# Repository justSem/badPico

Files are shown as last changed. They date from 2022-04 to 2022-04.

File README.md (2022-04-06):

# badPico!
An [RP2040](https://www.raspberrypi.com/products/rp2040/) mini-sized BadUSB clone

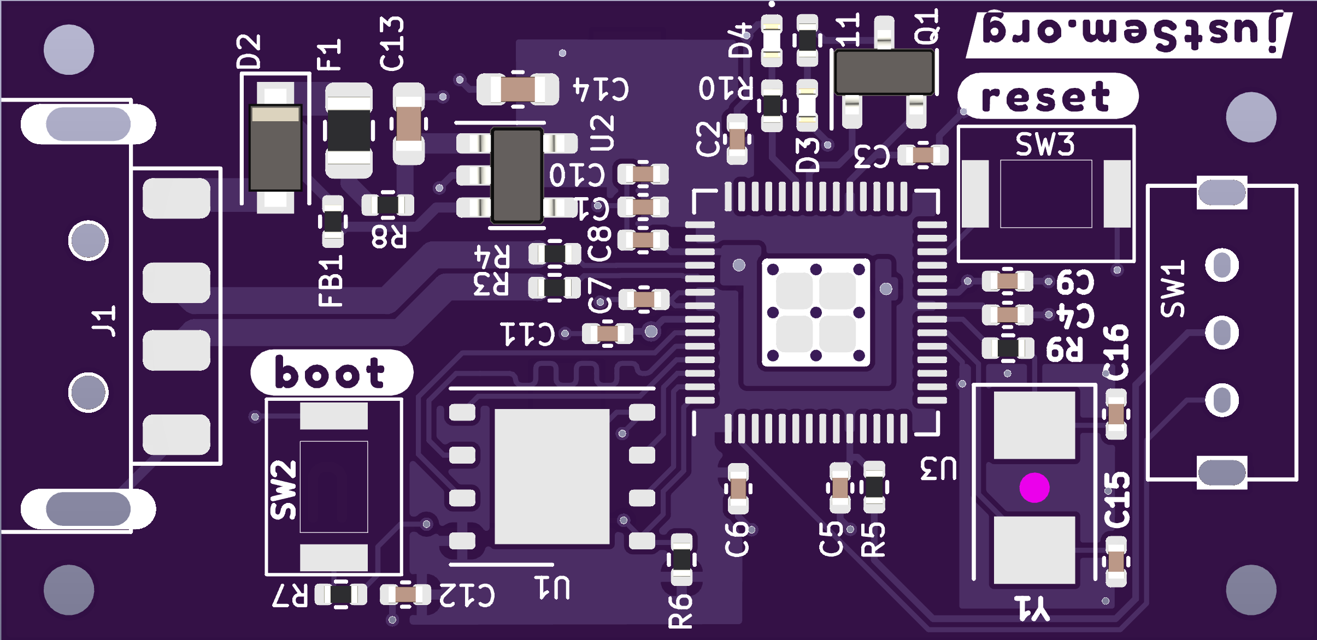
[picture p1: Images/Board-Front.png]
front

_Size: 19x39mm_

This tiny (19x34mm) device is just a common "Rubber Ducky" clone.

Without software this is just an RP2040-on-a-stick ;)

# Usage
A good starting point for this board is the [BadPico Repository](https://github.com/EvgeniGenchev/BadPico) by @EvgeniGenchev.

The board in general works identical to a Raspberry [Pi Pico](https://www.raspberrypi.com/products/raspberry-pi-pico/) and can be programmed as such.
However, due to the intended use-case the I/O pins are not available for usage with the exception of those listed below.

# PinOuts

| Designator	| GPIO  |  Type 	| Description 							|
| --- | ----- | --- | --- |
|  D4		| 25	| LED		| Status LED  							|
|  D3		| 24	| LED		| User-programmable LED 					|
| SW1		| 0	| Switch	| User-programmable switch. I use it as an 'arming' switch 	| 

# Bill of Materials (BoM)
| Name	| Designator	| Footprint	| Manufacturer		| Man. Part No.			|
| ----- | --- | --- | --- | --- |
| 27pF	| C15,C16	| C0402		| FH			| 0402CG270J500NT		|
| 100nF | C1-C9,C12	| C0402		| Yaego			| CC0402KRX7R7BB104		|
| 1uF	| C10,C11	| C0402		| Samsung		| CL05A105KQ5NNNC		|
| 10uF	| C13,C14	| C0603		| Samsung		| CL10A106MP8NNNC		| 
| Y	| Y1		| 5032		| Abracon		| ABMM2-12.000MHZ-E2-T 		|
| 24.7R	| R3,R4		| R0402		| FH			| RC-02W27R4FT 			|
| 330R	| R5		| R0402		| FOJAN			| FRC1206J331			|
| 1k	| R7,R9,R10,R11	| R0402		| Walsin		| MR04X102			|
| 100k	| R8		| R0402		| FH			| RS-03K104JT			|
| Flash	| U1		| WSON-8	| Winbond Elec		| W25Q128JVPIQ			|
| LDO	| U2		| TSOT-23-5	| Maxlinear		| SPX3819M5-L-3-3		|
| RP2040 | U3		| QFN-56	| Raspberry Pi		| RP2040			|
| FET	| Q1		| SOT-24	| Vishay		| Si2319CDS			|
| Diode	| D2		| SOD_123F	| Shandong		| 1N4002W			|
| LEDs	| D3,D4		| D0402		| Everlight		| 17-21/BHC-XL2M2TY/3T		|
| Fuse	| F1		| F0805		| LittelFuse		| 0805L050WR			|
| Bead	| FB1		| F0402		| Chillsin		| BBSY00100505101Y00		|
| USB	| J1		| Custom	| XKB Connectivity	| U217-041N-4BV81 		|
| SWT	| SW2,SW3	| Custom	| ALPS			| SKRKAEE020			|
| SWF	| SW1		| Custom	| Shou Han		| SK12D07VG4			|

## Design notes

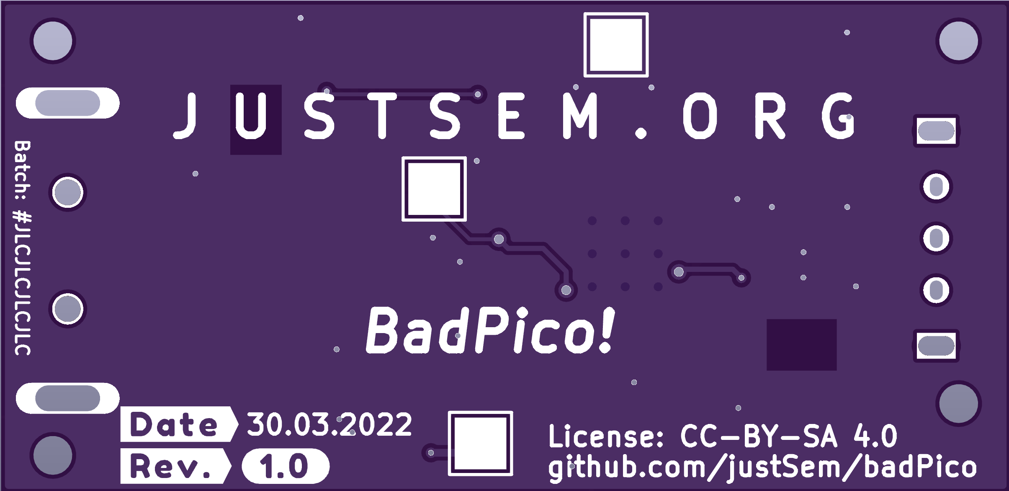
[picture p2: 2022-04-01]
Images/Board-Back.png

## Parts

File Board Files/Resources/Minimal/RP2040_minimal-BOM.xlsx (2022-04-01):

RP2040_minimal_r1 BOM
Item | Quantity | Reference | Part | Voltage | Current | Power | Material | Size | Tolerance | Manufacturer | Manuf. Part # | Description | Notes
1 | 3 | C1,C4,C17 | 10u | 16V |  |  | X5R | 0805_2012Metric | 10% | Murata | GRM21BR61C106KE15K | CAP CER 10UF 16V X5R 0805 | Or equivalent
2 | 2 | C2, C3 | 27p | 50V |  |  | C0G | 0402_1005Metric | 5% | Murata | GCM1555C1H270JA16D | CAP CER 27PF 50V C0G/NP0 0402 | Or equivalent
3 | 10 | C5, C6, C7, C9, C11, C12, C13, C14, C15, C16 | 100n | 25V |  |  | X7R | 0402_1005Metric | 10% | Murata | GRM155R71E104KE14J | CAP CER 0.1UF 25V X7R 0402 | Or equivalent
4 | 2 | C8, C10 | 1u | 10V |  |  | X6S | 0402_1005Metric | 10% | Murata | GRM155C81A105KA12D | CAP CER 1UF 10V X6S 0402 | Or equivalent
5 | 1 | J1 | USB_B_Micro |  |  |  |  |  |  | Amphenol | 10103594-0001LF | CONN RCPT USB2.0 MICRO B SMD R/A | Or equivalent
6 | 1 | J2 | 1x2 way header |  |  |  |  |  |  | Samtec | TSW-102-23-T-S | 2.54mm pin header 1x2 | Or equivalent
7 | 2 | J3, J4 | 2x18 way header |  |  |  |  |  |  | Samtec | TSW-118-23-T-D | 2.54mm pin header 2x18 | Or equivalent
8 | 2 | R1, R5 | 1k |  |  | 63mW |  | 0402_1005Metric | 1% | Yageo | RC0402FR-071KP | RES SMD 1K OHM 1% 1/16W 0402 | Or equivalent
9 | 1 | R2 | DNF |  |  |  |  | 0402_1005Metric |  |  |  |  | Do Not Fit
10 | 2 | R3, R4 | 27.4 |  |  | 63mW |  | 0402_1005Metric | 1% | Yageo | RC0402FR-0727R4L | RES SMD 27.4 OHM 1% 1/16W 0402 | Or equivalent
11 | 1 | U1 | NCP1117-3.3 |  |  |  |  | SOT-223-3 |  | ON Semiconductor | NCP1117ST33T3G | IC REG LINEAR 3.3V 1A SOT223
12 | 1 | U2 | W25Q128JVS |  |  |  |  | SOIC-8 |  | Winbond | W25Q128JVSIQ TR | IC FLASH 128M SPI 133MHZ 8SOIC
13 | 1 | U3 | RP2040 |  |  |  |  | QFN56 |  | Raspberry Pi | RP2040
14 | 1 | Y1 | ABLS-12.000MHZ-B4-T |  |  |  |  | HC49-US |  | Abracon | ABLS-12.000MHZ-B4-T | CRYSTAL 12.0000MHZ 18PF SMD

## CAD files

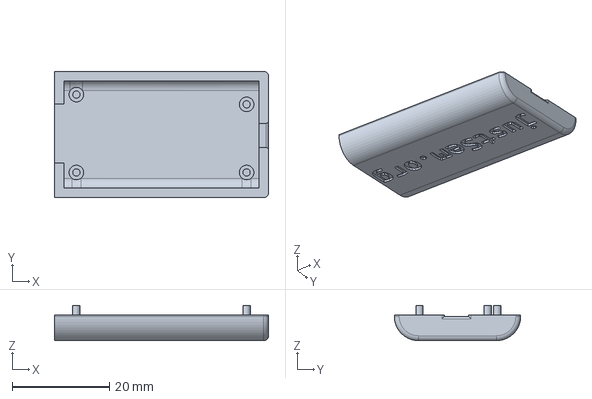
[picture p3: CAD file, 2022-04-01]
3D/BadPioco-Btm.step
44.0 x 26.0 x 7.25 mm

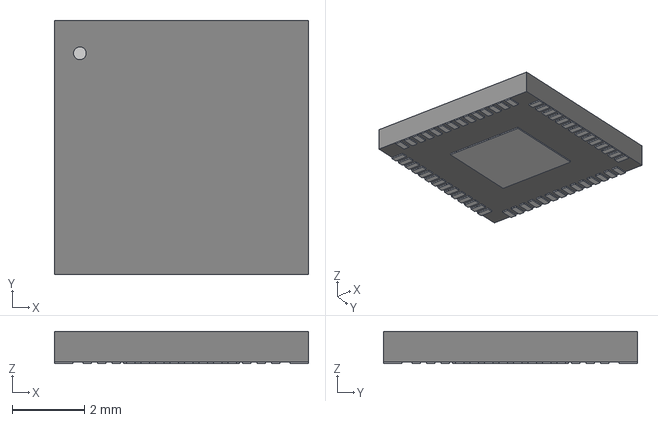
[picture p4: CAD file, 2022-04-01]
Board Files/Resources/Minimal/QFN56_7X7_RPI.step
7.01 x 7.01 x 0.892 mm

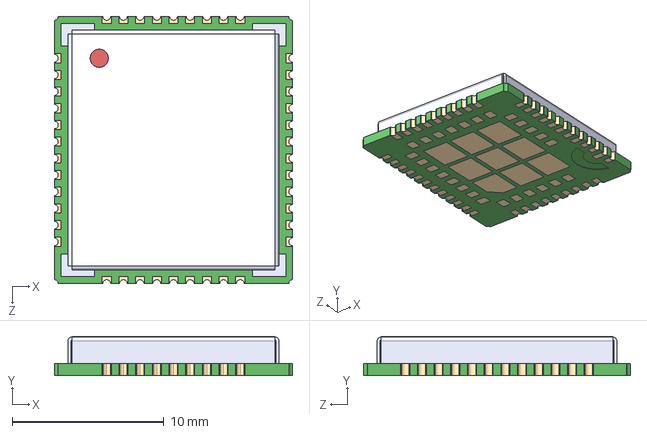
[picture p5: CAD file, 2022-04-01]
Board Files/Resources/SIM868/SIM868.step
15.7 x 2.60 x 17.6 mm

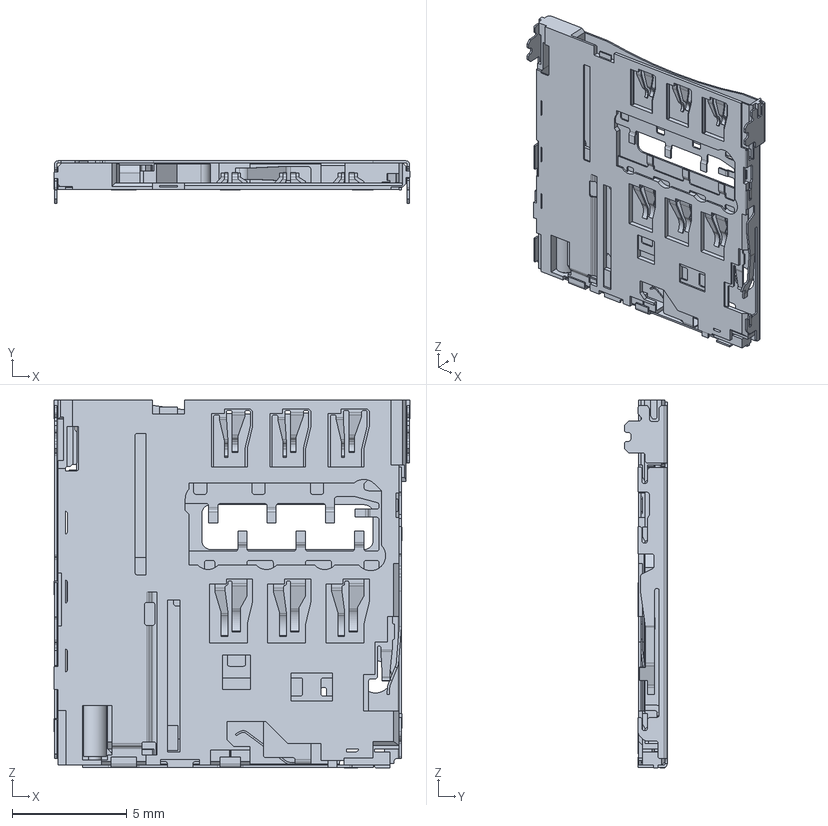
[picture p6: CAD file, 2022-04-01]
Board Files/Resources/ul_2822541-1/c-2822541-1-c-3d.stp
15.5 x 1.89 x 16.0 mm

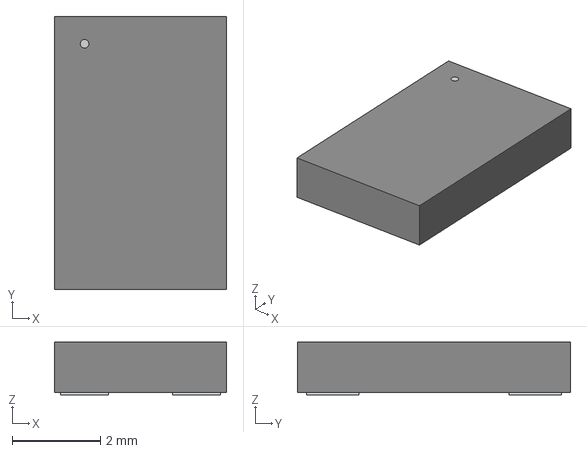
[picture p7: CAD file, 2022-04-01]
Board Files/Resources/ul_ABMM2-12-000MHZ-E2-T/CRYSTAL_ABMM2_ABR.step
3.91 x 6.20 x 1.20 mm

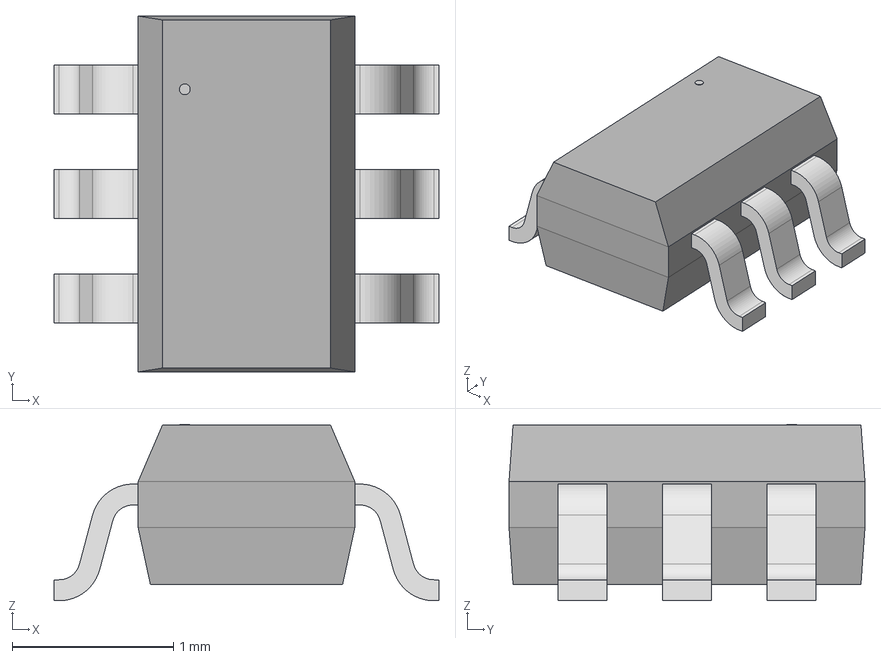
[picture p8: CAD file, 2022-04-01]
Board Files/Resources/ul_ESDA6V1-5W6/STEP/SOT323-6L_STM.step
2.39 x 2.21 x 1.09 mm

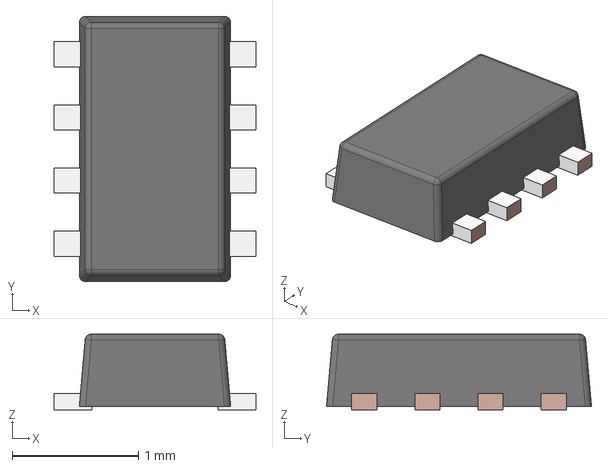
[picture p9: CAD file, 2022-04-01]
Board Files/Resources/ul_LM66200DRLR/STEP/DRL0008A.stp
1.60 x 2.10 x 0.6 mm
FRAME-DRL0008A
BODY-SOT

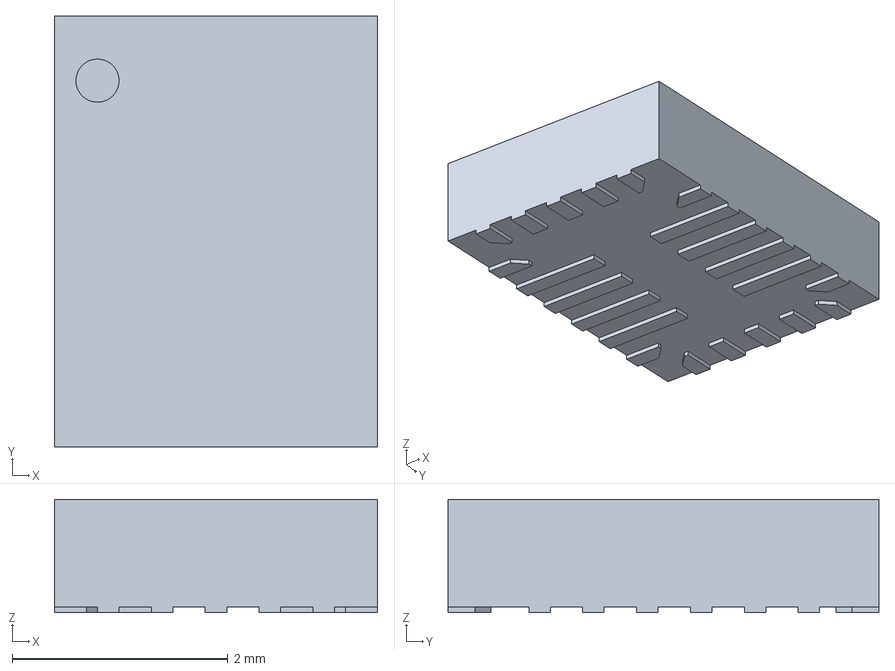
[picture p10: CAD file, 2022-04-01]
Board Files/Resources/ul_MP2624GL/FreeCad.step
3.00 x 4.00 x 1.05 mm

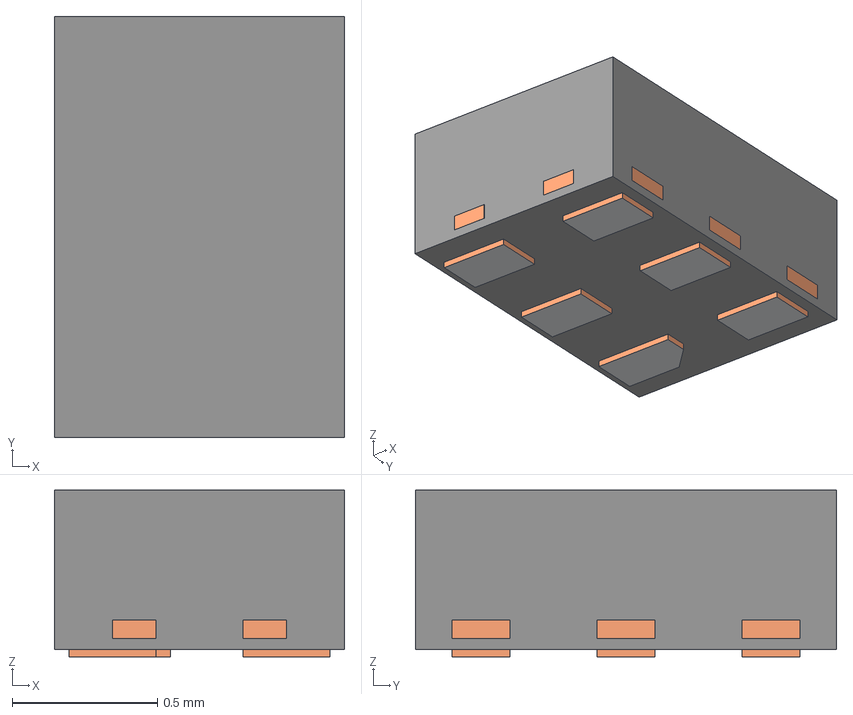
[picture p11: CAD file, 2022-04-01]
Board Files/Resources/ul_SN74LVC1G66DRYR/DRY0006A.stp
1.00 x 1.45 x 0.575 mm
BODY-SON
FRAME-DRY0006A
PIN1-ID

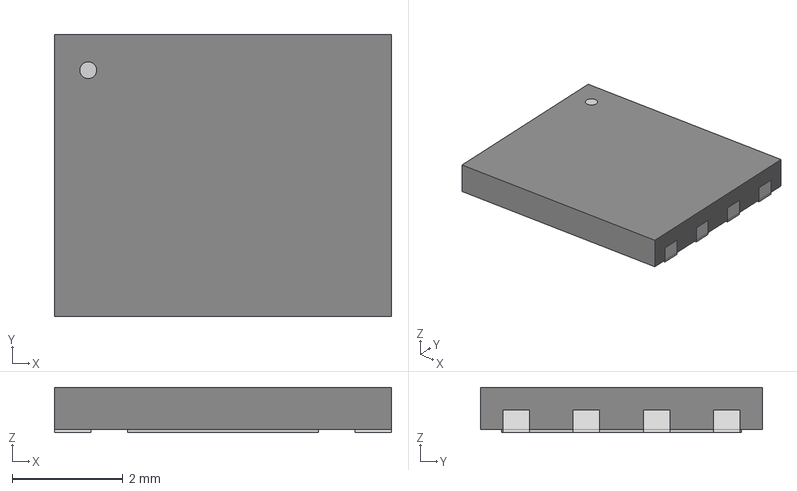
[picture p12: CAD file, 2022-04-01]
Board Files/Resources/Winbond_Flash/WSON-8_6X5_WIN.step
6.10 x 5.11 x 0.815 mm

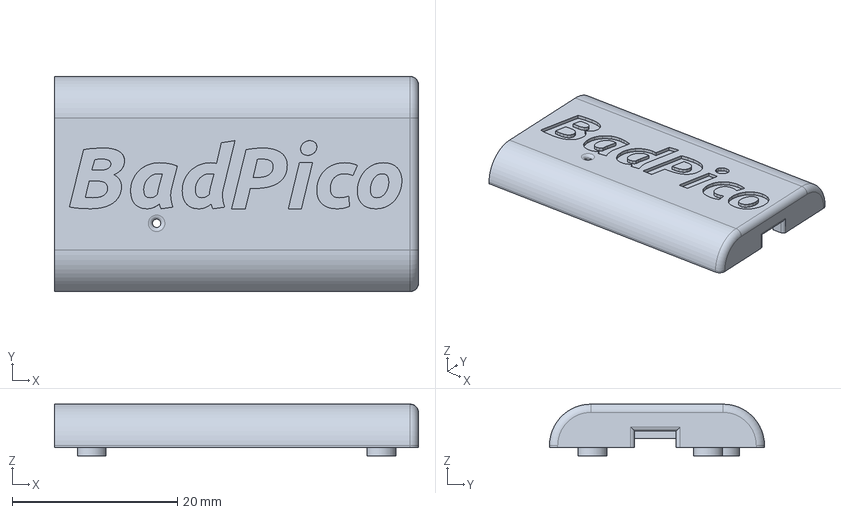
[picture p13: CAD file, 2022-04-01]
3D/BadPioco.FCStd
44.0 x 26.0 x 6.25 mm

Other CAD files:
3D/BadPioco-Top.step
3D/BadPioco-Btm.stl

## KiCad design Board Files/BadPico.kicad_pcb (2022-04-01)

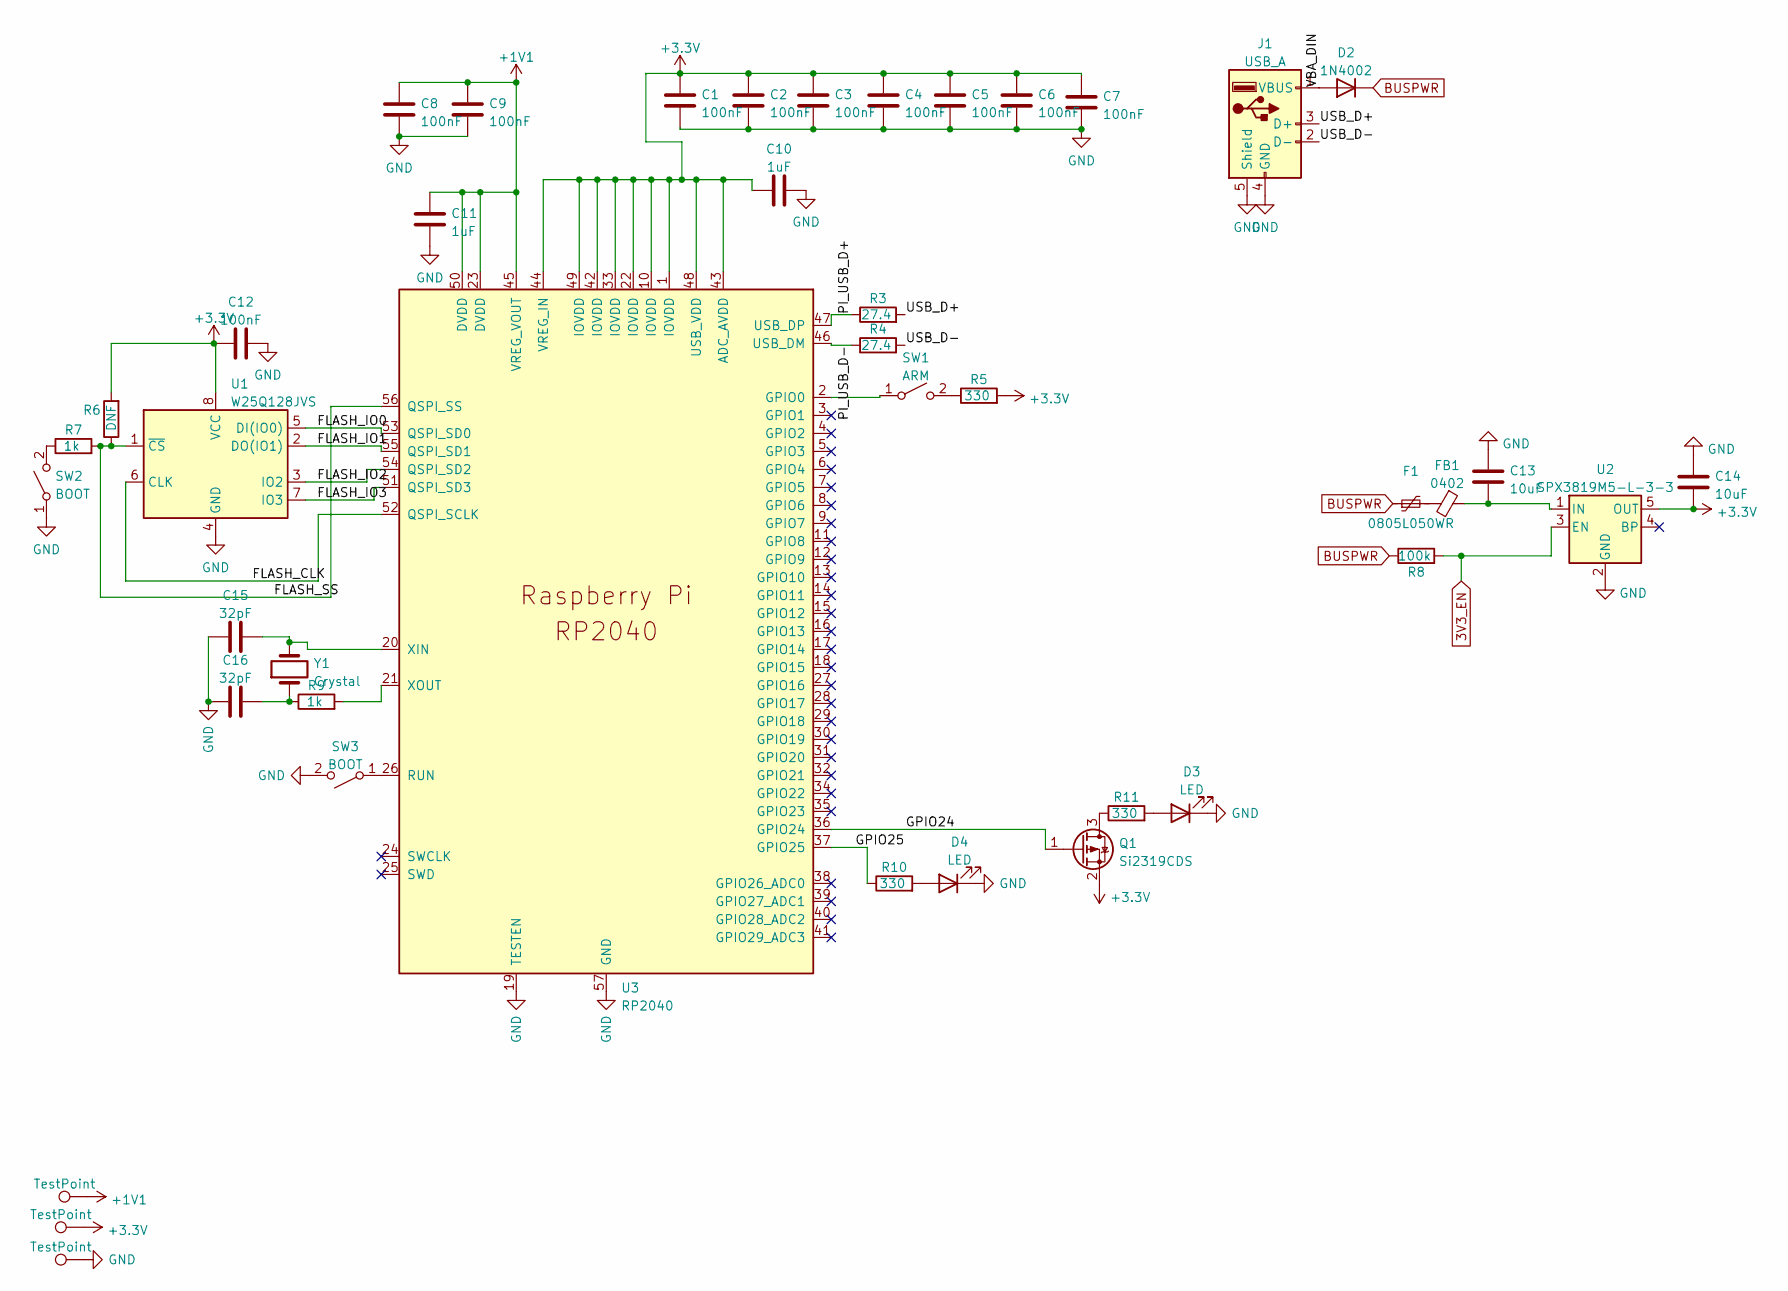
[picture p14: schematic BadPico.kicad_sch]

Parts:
C1, C2, C3, C4, C5, C6, C7, C8, C9, C12: 100nF; C_0402_1005Metric
C10, C11: 1uF; C_0402_1005Metric
C13, C14: 10uF; C_0603_1608Metric
C15, C16: 32pF; C_0402_1005Metric
D2: 1N4002; D_SOD-123F
D3, D4: LED; LED_0402_1005Metric
F1: 0805L050WR; Fuse_0805_2012Metric
FB1: 0402; R_0402_1005Metric
J1: USB_A; Male_Type-A-XKB-U217-041N-4BV81
Q1: Si2319CDS; SOT-23
R3, R4: 27.4; R_0402_1005Metric
R5, R10, R11: 330; R_0402_1005Metric
R6: DNF; R_0402_1005Metric
R7, R9: 1k; R_0402_1005Metric
R8: 100k; R_0402_1005Metric
SW1: ARM; SW_DPDT_SK12D07VG4
SW2, SW3: BOOT; SW_SPST_ALPS_SKRKAEE020
TP3, TP4, TP5: TestPoint; TestPoint_Pad_2.0x2.0mm
U1: W25Q128JVS; WSON-8-1EP_6x5mm_P1.27mm_EP3.4x4mm
U2: SPX3819M5-L-3-3; SOT-23-5
U3: RP2040; RP2040-QFN-56
Y1: Crystal; Crystal_SMD_5032-2Pin_5.0x3.2mm

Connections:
3V3_EN: R8.2, U2.3 (EN)
+1V1: C8.1, C9.1, C11.2, TP3.1, U3.23 (DVDD), U3.45 (VREG_VOUT), U3.50 (DVDD)
+3V3: C1.1, C2.1, C3.1, C4.1, C5.1, C6.1, C7.1, C10.1, C12.1, C14.1, Q1.2 (S), R5.2, R6.2, TP4.1, U1.8 (VCC), U2.5 (OUT), U3.1 (IOVDD), U3.10 (IOVDD), U3.22 (IOVDD), U3.33 (IOVDD), U3.42 (IOVDD), U3.43 (ADC_AVDD), U3.44 (VREG_IN), U3.48 (USB_VDD), U3.49 (IOVDD)
/FLASH_CLK: U1.6 (CLK), U3.52 (QSPI_SCLK)
/FLASH_IO0: U1.5 (DI(IO0)), U3.53 (QSPI_SD0)
/FLASH_IO1: U1.2 (DO(IO1)), U3.55 (QSPI_SD1)
/FLASH_IO2: U1.3 (IO2), U3.54 (QSPI_SD2)
/FLASH_IO3: U1.7 (IO3), U3.51 (QSPI_SD3)
/FLASH_SS: R6.1, R7.2, U1.1 (~CS), U3.56 (QSPI_SS)
/GPIO24: Q1.1 (G), U3.36 (GPIO24)
/GPIO25: R10.1, U3.37 (GPIO25)
/PI_USB_D+: R3.1, U3.47 (USB_DP)
/PI_USB_D-: R4.1, U3.46 (USB_DM)
/USB_D+: J1.3 (D+), R3.2
/USB_D-: J1.2 (D-), R4.2
/VBA_DIN: D2.2 (A), J1.1 (VBUS)
BUSPWR: D2.1 (K), F1.1, R8.1
GND: C1.2, C2.2, C3.2, C4.2, C5.2, C6.2, C7.2, C8.2, C9.2, C10.2, C11.1, C12.2, C13.2, C14.2, C15.2, C16.2, D3.1 (K), D4.1 (K), J1.4 (GND), J1.5 (Shield), SW2.1 (A), SW3.2 (B), TP5.1, U1.4 (GND), U1.9, U2.2 (GND), U3.19 (TESTEN), U3.57 (GND)
unnamed: C13.1, FB1.1, U2.1 (IN)
unnamed: C15.1, U3.20 (XIN), Y1.2
unnamed: C16.1, R9.1, Y1.1
unnamed: D3.2 (A), R11.2
unnamed: D4.2 (A), R10.2
unnamed: F1.2, FB1.2
unnamed: Q1.3 (D), R11.1
unnamed: R7.1, SW2.2 (B)
unnamed: R9.2, U3.21 (XOUT)
unnamed: R5.1, SW1.2 (B)
unnamed: SW3.1 (A), U3.26 (RUN)
unnamed: SW1.1 (A), U3.2 (GPIO0)

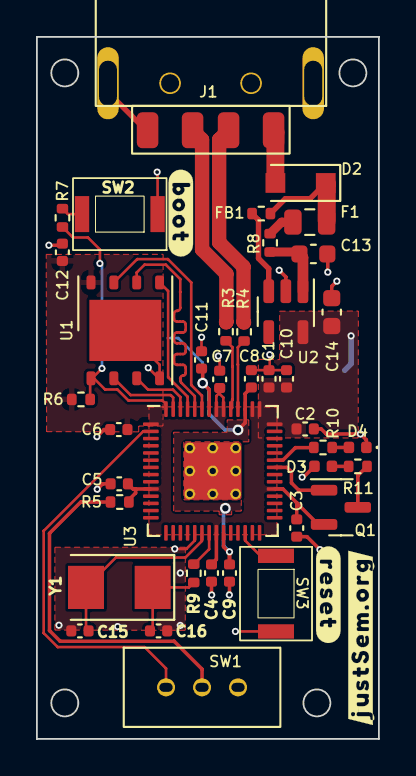
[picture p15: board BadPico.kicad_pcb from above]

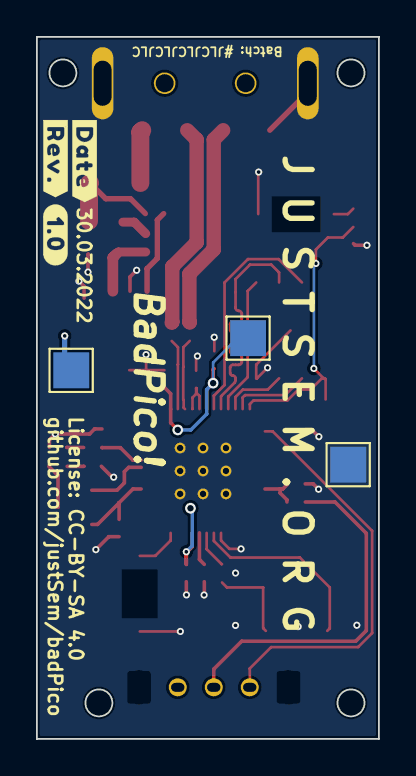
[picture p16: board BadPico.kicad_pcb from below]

Board: 2 copper layers, 19.0 x 39.0 mm, 42 parts (3 on the bottom side), 30 nets.

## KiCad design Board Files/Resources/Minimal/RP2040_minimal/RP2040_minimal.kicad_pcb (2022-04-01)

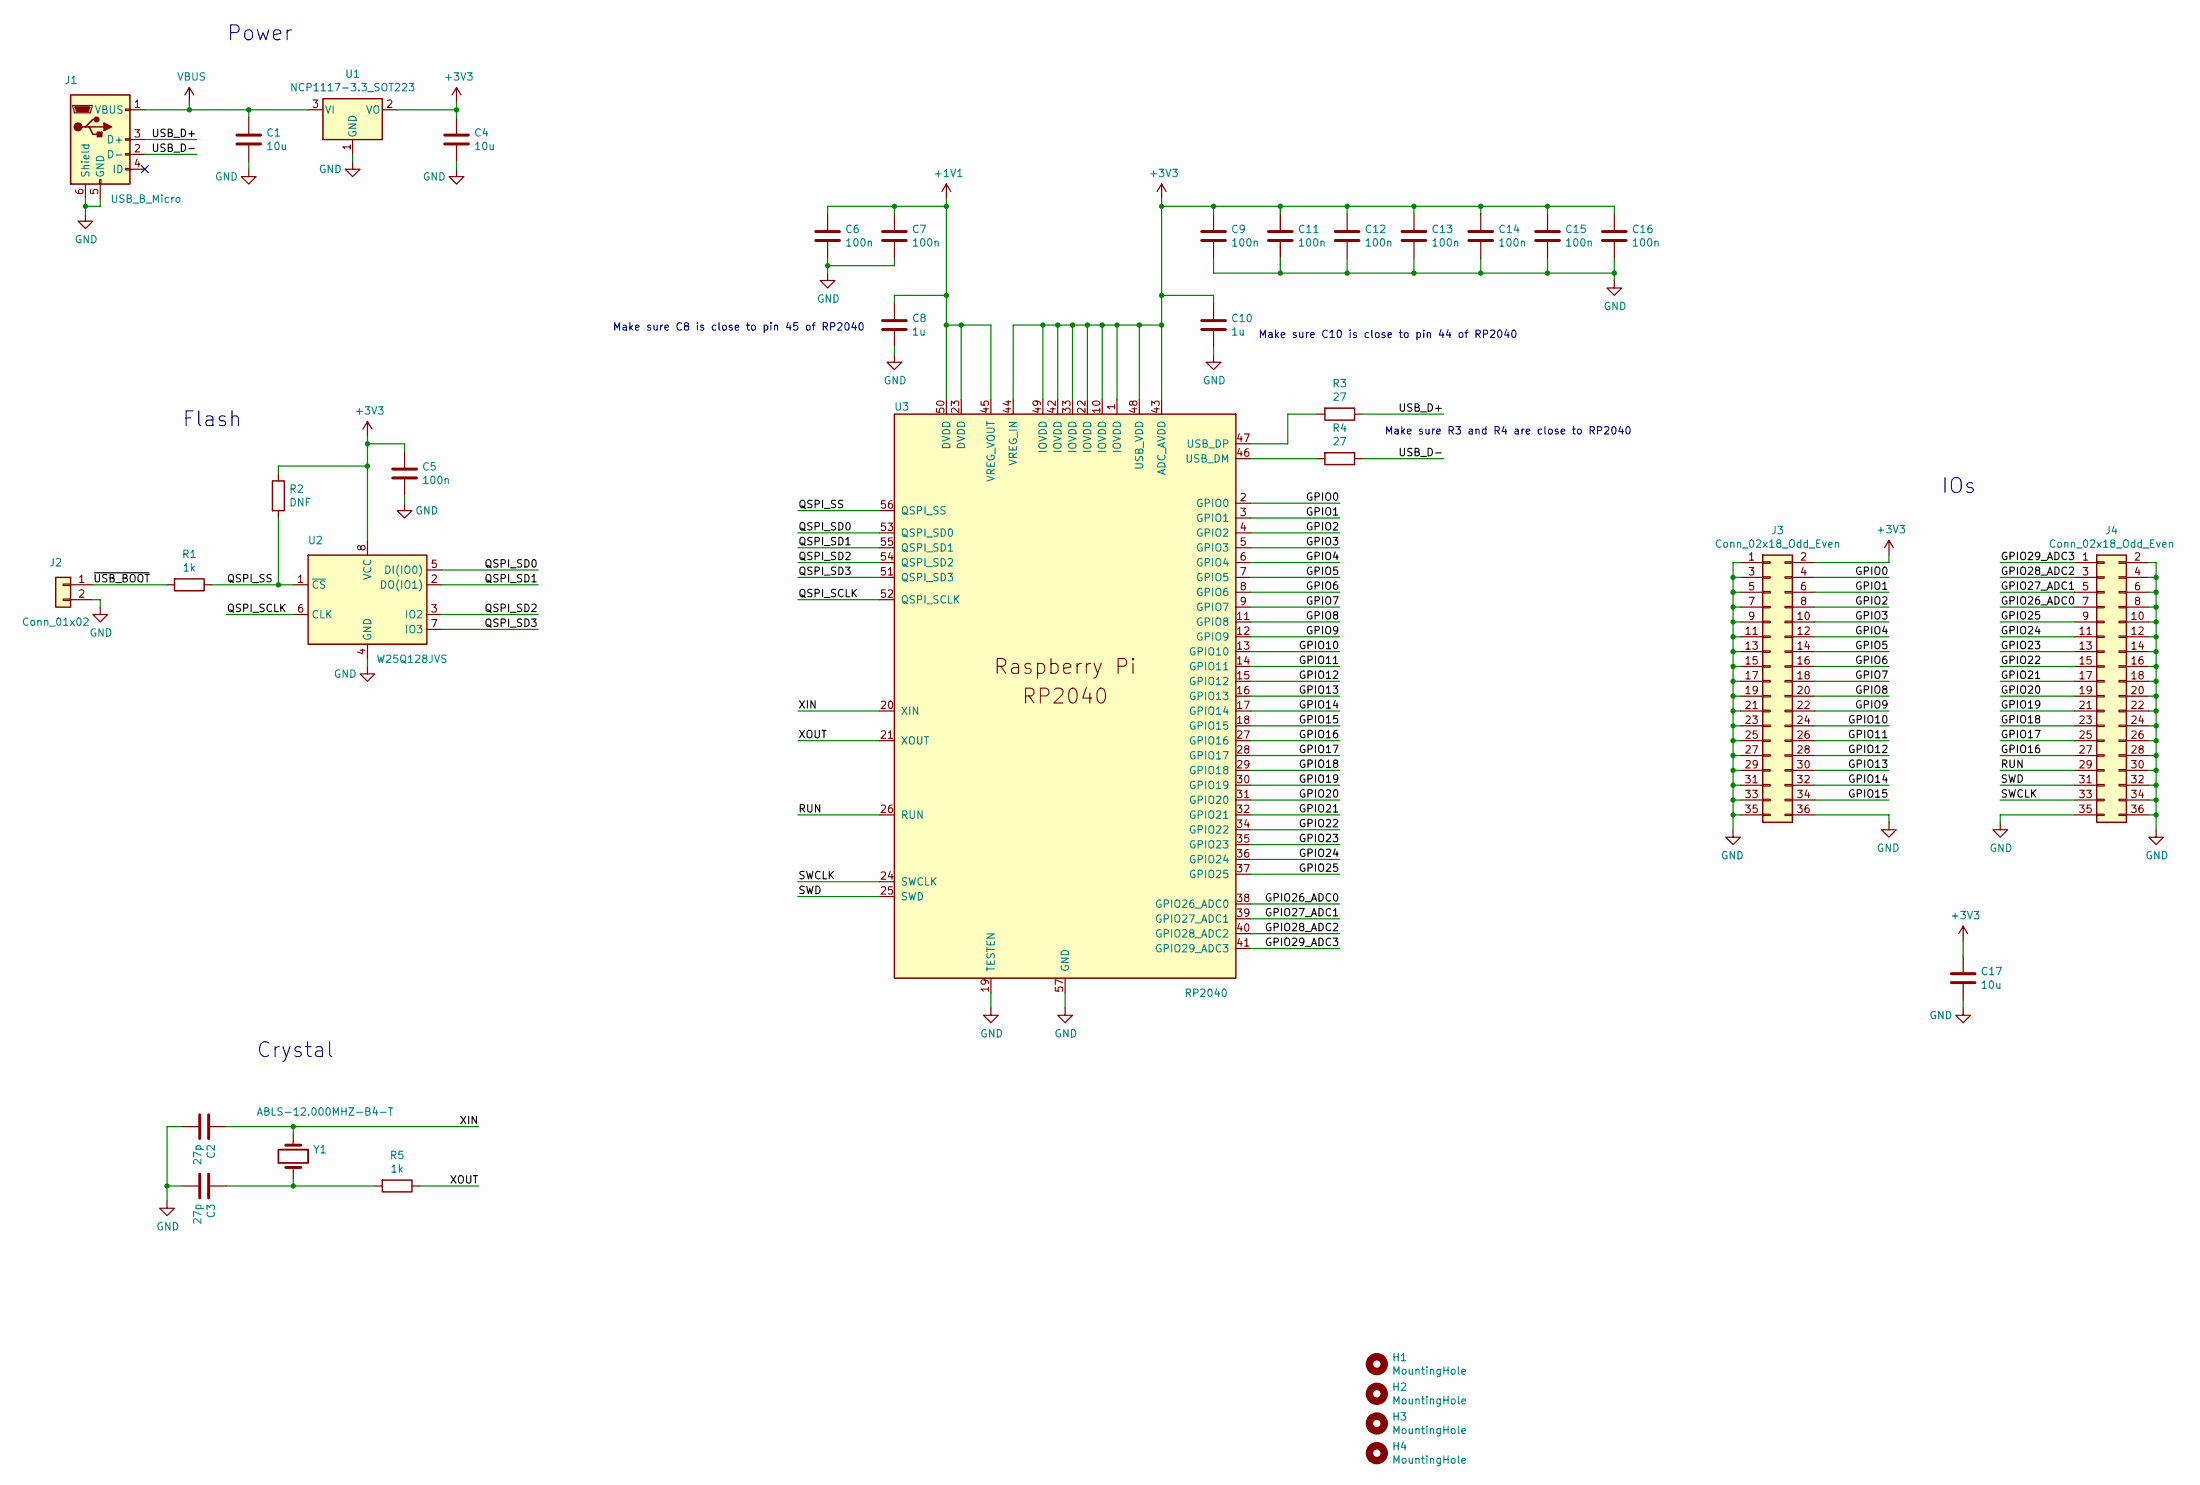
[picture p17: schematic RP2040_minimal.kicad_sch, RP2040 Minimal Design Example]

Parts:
C1, C4, C17: 10u; C_0805_2012Metric
C2, C3: 27p; C_0402_1005Metric
C5, C6, C7, C9, C11, C12, C13, C14, C15, C16: 100n; C_0402_1005Metric
C8, C10: 1u; C_0402_1005Metric
H1, H2, H3, H4: MountingHole; MountingHole_2.7mm_M2.5
J1: USB_B_Micro; USB_Micro-B_Amphenol_10103594-0001LF_Horizontal_modified
J2: Conn_01x02; PinHeader_1x02_P2.54mm_Vertical
J3, J4: Conn_02x18_Odd_Even; PinHeader_2x18_P2.54mm_Vertical
R1, R5: 1k; C_0402_1005Metric
R2: DNF; C_0402_1005Metric
R3, R4: 27; C_0402_1005Metric
U1: NCP1117-3.3_SOT223; SOT-223-3_TabPin2
U2: W25Q128JVS; SOIC-8_5.23x5.23mm_P1.27mm
U3: RP2040; RP2040-QFN-56
Y1: ABLS-12.000MHZ-B4-T; Crystal_SMD_HC49-US

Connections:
+1V1: C6.1, C7.1, C8.1, U3.23 (DVDD), U3.45 (VREG_VOUT), U3.50 (DVDD)
+3V3: C4.1, C5.1, C9.1, C10.1, C11.1, C12.1, C13.1, C14.1, C15.1, C16.1, C17.1, J3.2, R2.1, U1.2 (VO), U2.8 (VCC), U3.1 (IOVDD), U3.10 (IOVDD), U3.22 (IOVDD), U3.33 (IOVDD), U3.42 (IOVDD), U3.43 (ADC_AVDD), U3.44 (VREG_IN), U3.48 (USB_VDD), U3.49 (IOVDD)
/GPIO0: J3.4, U3.2 (GPIO0)
/GPIO1: J3.6, U3.3 (GPIO1)
/GPIO2: J3.8, U3.4 (GPIO2)
/GPIO3: J3.10, U3.5 (GPIO3)
/GPIO4: J3.12, U3.6 (GPIO4)
/GPIO5: J3.14, U3.7 (GPIO5)
/GPIO6: J3.16, U3.8 (GPIO6)
/GPIO7: J3.18, U3.9 (GPIO7)
/GPIO8: J3.20, U3.11 (GPIO8)
/GPIO9: J3.22, U3.12 (GPIO9)
/GPIO10: J3.24, U3.13 (GPIO10)
/GPIO11: J3.26, U3.14 (GPIO11)
/GPIO12: J3.28, U3.15 (GPIO12)
/GPIO13: J3.30, U3.16 (GPIO13)
/GPIO14: J3.32, U3.17 (GPIO14)
/GPIO15: J3.34, U3.18 (GPIO15)
/GPIO16: J4.27, U3.27 (GPIO16)
/GPIO17: J4.25, U3.28 (GPIO17)
/GPIO18: J4.23, U3.29 (GPIO18)
/GPIO19: J4.21, U3.30 (GPIO19)
/GPIO20: J4.19, U3.31 (GPIO20)
/GPIO21: J4.17, U3.32 (GPIO21)
/GPIO22: J4.15, U3.34 (GPIO22)
/GPIO23: J4.13, U3.35 (GPIO23)
/GPIO24: J4.11, U3.36 (GPIO24)
/GPIO25: J4.9, U3.37 (GPIO25)
/GPIO26_ADC0: J4.7, U3.38 (GPIO26_ADC0)
/GPIO27_ADC1: J4.5, U3.39 (GPIO27_ADC1)
/GPIO28_ADC2: J4.3, U3.40 (GPIO28_ADC2)
/GPIO29_ADC3: J4.1, U3.41 (GPIO29_ADC3)
/QSPI_SCLK: U2.6 (CLK), U3.52 (QSPI_SCLK)
/QSPI_SD0: U2.5 (DI(IO0)), U3.53 (QSPI_SD0)
/QSPI_SD1: U2.2 (DO(IO1)), U3.55 (QSPI_SD1)
/QSPI_SD2: U2.3 (IO2), U3.54 (QSPI_SD2)
/QSPI_SD3: U2.7 (IO3), U3.51 (QSPI_SD3)
/QSPI_SS: R1.1, R2.2, U2.1 (~CS), U3.56 (QSPI_SS)
/RUN: J4.29, U3.26 (RUN)
/SWCLK: J4.33, U3.24 (SWCLK)
/SWD: J4.31, U3.25 (SWD)
/USB_D+: J1.3 (D+), R3.1
/USB_D-: J1.2 (D-), R4.1
/XIN: C2.1, U3.20 (XIN), Y1.1
/XOUT: R5.1, U3.21 (XOUT)
/~USB_BOOT: J2.1, R1.2
GND: C1.2, C2.2, C3.2, C4.2, C5.2, C6.2, C7.2, C8.2, C9.2, C10.2, C11.2, C12.2, C13.2, C14.2, C15.2, C16.2, C17.2, J1.5 (GND), J1.6 (Shield), J2.2, J3.1, J3.3, J3.5, J3.7, J3.9, J3.11, J3.13, J3.15, J3.17, J3.19, J3.21, J3.23, J3.25, J3.27, J3.29, J3.31, J3.33, J3.35, J3.36, J4.2, J4.4, J4.6, J4.8, J4.10, J4.12, J4.14, J4.16, J4.18, J4.20, J4.22, J4.24, J4.26, J4.28, J4.30, J4.32, J4.34, J4.35, J4.36, U1.1 (GND), U2.4 (GND), U3.19 (TESTEN), U3.57 (GND)
unnamed: C3.1, R5.2, Y1.2
unnamed: R3.2, U3.47 (USB_DP)
unnamed: R4.2, U3.46 (USB_DM)
VBUS: C1.1, J1.1 (VBUS), U1.3 (VI)

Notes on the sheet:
Make sure R3 and R4 are close to RP2040
Make sure C10 is close to pin 44 of RP2040
Make sure C8 is close to pin 45 of RP2040
IOs
Power
Crystal
Flash

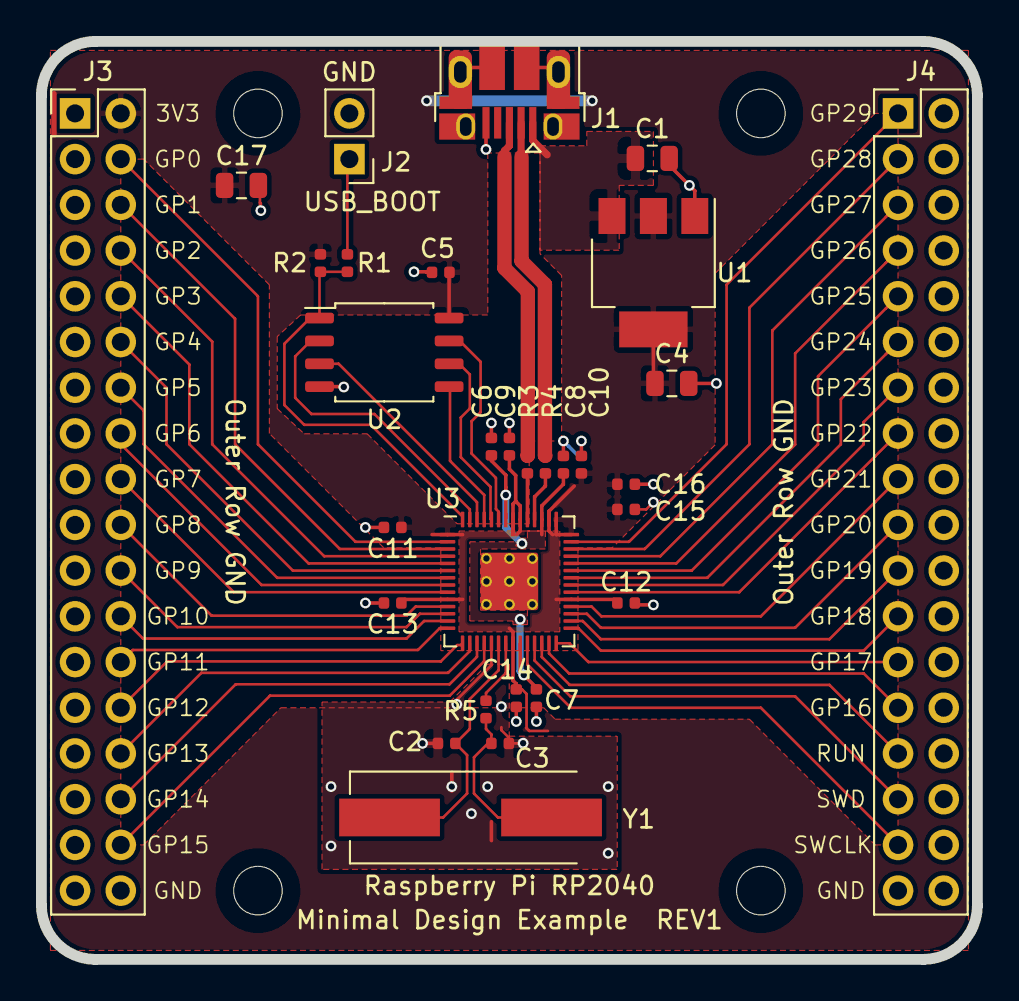
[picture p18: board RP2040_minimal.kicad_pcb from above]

Board: 2 copper layers, 52.0 x 51.0 mm, 34 parts (0 on the bottom side), 51 nets.

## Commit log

2022-04-01 Rev 1.0
    [BadPico-B_Cu.gbr, BadPico-B_Mask.gbr, BadPico-B_Paste.gbr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]
2022-04-01 Added board images

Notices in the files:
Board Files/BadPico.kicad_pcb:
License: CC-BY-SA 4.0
